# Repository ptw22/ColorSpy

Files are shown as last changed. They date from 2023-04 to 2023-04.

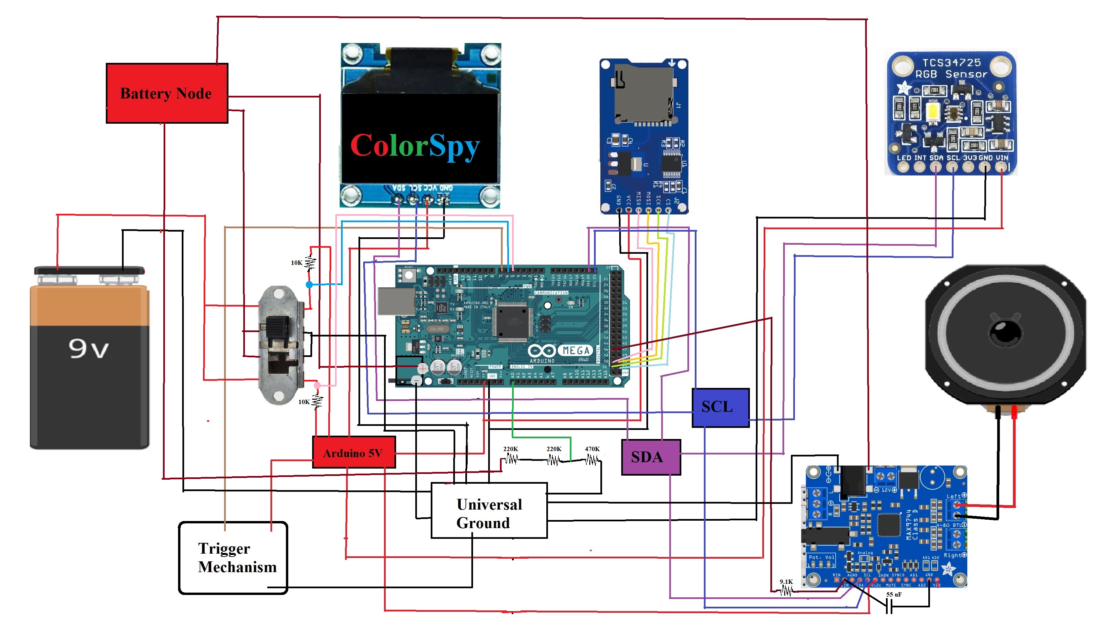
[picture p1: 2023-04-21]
colorpsydiagram.jpg

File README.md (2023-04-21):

# ColorSpy

Start with the ColorSpyInstructionManual file. Use the circuit diagram to guide you in building the circuit. Ensure relevant libraries are imported into your Arduino libraries folder. You can use the STL files to 3D print the housing for yourself.

*Disclaimer*: This project assumes the reader is familiar and experienced with safe soldering techniques, Arduino programming and battery handling. Always use best practices when handling electronic components, solder, soldering irons, and batteries. The uploaders of these files assume no liabilities for damaged micro controllers, injuries of other damage that may stem from accessing this information.

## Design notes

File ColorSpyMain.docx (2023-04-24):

#include "Wire.h"

#include "SPI.h"

#include "SD.h"

#include "TMRpcm.h"

#define SD_ChipSelectPin 53

#define MAX9744_I2CADDR 0x4B

#include "Adafruit_TCS34725.h"

#include <Adafruit_SSD1306.h>

#include <Adafruit_GFX.h>

#define OLED_ADDR 0x3C

Adafruit_SSD1306 display(-1);

int value; //value for the "voltage" read at analog pin

float voltage; //actual voltage after doing voltage divider calculations

float R1 = 44.0; //Resistor 1 value in voltage divider this is 440k for this i have two 220k in series

float R2 = 47.0; //Resistor 2 value in voltage divider this is 470k

int fullyDischargedVoltage=7; //fuly discharged voltage value for vattery

int fullyChargedVoltage=9; //fuly charged voltage value for vattery

int percentage; //percentage of battery remaining

int pin5; //initialization of pin 7

int pin6; //initialization of pin 6

TMRpcm tmrpcm;

int8_t thevol;

int val;

Adafruit_TCS34725 tcs = Adafruit_TCS34725(TCS34725_INTEGRATIONTIME_50MS, TCS34725_GAIN_1X);

//function to draw horizontal lines for battery

void drawLineH(int start, int end, int row) {

int i = start;

while (i <= end) {

display.drawPixel(i, row, WHITE); //command to display pixel (column, row, color)

i++; //We dont have color but it has to be there

}

}

//function to draw vertical lines for battery

void drawLineV(int start, int end, int column) {

int j = start;

while (j <= end) {

display.drawPixel(column, j, WHITE); //command to display pixel (column, row, color)

j++;

}

}

//function to draw battery border

void screenSetup(){

// code for the battery horizontal border

drawLineH(93, 126, 0);

drawLineH(93, 126, 7);

// code for the battery vertical border

drawLineV(1, 6, 92);

drawLineV(1, 6, 127);

// code for the battery tip

drawLineH(88, 91, 2);

drawLineH(88, 91, 3);

drawLineH(88, 91, 4);

drawLineH(88, 91, 5);

}

//function for the block 1 inside battery

void block1(){

drawLineH(95, 100, 2);

drawLineH(95, 100, 3);

drawLineH(95, 100, 4);

drawLineH(95, 100, 5);

}

//function for the block 2 inside battery

void block2(){

drawLineH(103, 108, 2);

drawLineH(103, 108, 3);

drawLineH(103, 108, 4);

drawLineH(103, 108, 5);

}

//function for the block 3 inside battery

void block3(){

drawLineH(111, 116, 2);

drawLineH(111, 116, 3);

drawLineH(111, 116, 4);

drawLineH(111, 116, 5);

}

//function for the block 4 inside battery

void block4(){

drawLineH(119, 124, 2);

drawLineH(119, 124, 3);

drawLineH(119, 124, 4);

drawLineH(119, 124, 5);

}

//function to measure voltage, do percentage calulcation, then display the corresponding number of blocks in the battery

void battery(){

value = analogRead(A0); //reads the value at the analog pin

voltage = 1.1 * value * (5.0/1024)*((R1 + R2)/R2); //1.04 is correction factor, 5/1024 is to get the bits or whatever multiplied by reciprocal of voltage divider

percentage = (voltage - fullyDischargedVoltage) / (fullyChargedVoltage - fullyDischargedVoltage) * 100; //calculated the percentage of the battery remaining

percentage = (percentage/10)*10; //This makes the percentage increment in increments of 10

screenSetup(); //calls screenSetup function to put the borders of the battery on the screen

if (percentage >= 80){

block1();

block2();

block3();

block4();

}

else if (percentage < 80 && percentage >= 60){

block2();

block3();

block4();

}

else if (percentage < 60 && percentage >= 40){

block3();

block4();

}

else if (percentage < 40 && percentage >= 20){

block4();

}

else if (percentage < 20 && percentage >= 0){

//empty on purpose

}

}

class ColorName { //creates a private class color name which will be used to create our predetermined color value objects.

protected: //safe variables that cannot be alterted by the sketch/ComputeMSE

String _name;

byte _red;

byte _green;

byte _blue;

public: //duplicate variables safe for manipulation

ColorName(String name, byte red, byte green, byte blue){

_name = name;

_red = red;

_green = green;

_blue = blue;

}

byte getRed(){ //gets protected variables and passes them into public domain

return _red;}

byte getGreen(){

return _green;}

byte getBlue(){

return _blue;}

String getName(){

return _name;}

long computeMse(byte red, byte green, byte blue) { //computes error between defined color and measured color using Mean square error method

return (long) (((long)(red - _red) * (red - _red) + (long)(green - _green) * (green - _green) + (long)(blue - _blue) * (blue - _blue)) / 3);

}

static ColorName* getClosestColorName(ColorName colorNames[],

unsigned int numColors, byte red, byte green, byte blue){ //takes in predetermined color array and predetermined color

//array size. also takes in measured RGB values

ColorName* _bestMatchColorName = NULL; //initializes best color name match pointer

long bestMatchDistance = 65535;

for(int i = 0; i < numColors; i++){ //iterate through all predetermined color objects and their values

ColorName* curColorName = &colorNames[i];

if(_bestMatchColorName == NULL){

_bestMatchColorName = &colorNames[0];

}

long meanSquareError = curColorName->computeMse(red, green, blue);

if(meanSquareError < bestMatchDistance){

_bestMatchColorName = &colorNames[i];

bestMatchDistance = meanSquareError;

}

}

return _bestMatchColorName;

}

};

const int NUM_COLOR_NAMES = 12; //defines the colors and their ideal values

ColorName _colorNames[NUM_COLOR_NAMES] = { //this can be adjusted to add more colors and better accuracy

ColorName("Purple", 78, 67, 102),

ColorName("Yellow", 106, 92, 42),

ColorName("Blue", 34, 88, 124),

ColorName("Green", 51, 114, 76),

ColorName("Red", 156, 47, 51),

ColorName("Black", 85, 84, 74),

ColorName("Orange", 157, 53, 36),

ColorName("White", 81, 85, 76),

ColorName("Brown", 112, 75, 58),

ColorName("Cyan", 50, 98, 96),

ColorName("Pink", 131, 55, 65),

ColorName("Lime", 80, 108, 51)

};

void setup() {

Serial.begin(9600); //Initializes Arduino

tmrpcm.speakerPin=46;

SD.begin(SD_ChipSelectPin); //Initialized SD Card

Wire.begin();

pinMode(6, INPUT);

pinMode(5, INPUT);

setvolume(60);

// initialize and clear display

display.begin(SSD1306_SWITCHCAPVCC, OLED_ADDR);

display.clearDisplay();

display.display(); //updates the display need this anytime you want to put something on the screen

float sensedRed, sensedGreen, sensedBlue;

tcs.getRGB(&sensedRed, &sensedGreen, &sensedBlue);

int rawRed = (int)sensedRed;

int rawGreen = (int)sensedGreen;

int rawBlue = (int)sensedBlue;

}

boolean setvolume(int8_t v) { //volume control function

Serial.println("accesses set volume function");

Wire.beginTransmission(MAX9744_I2CADDR);

Serial.println("begins volume transmission");

Wire.write(v);

Serial.println("writes volume");

if (Wire.endTransmission() == 0)

return true;

else

return false;

}

char hex(int n) {

if (n < 10) {

return char(n + 48); // 48 is the ASCII code for '0'

} else {

return char(n + 55); // 55 is the ASCII code for 'A' - 10

}

}

String RGBtoHex(int r, int g, int b) {

String hexCode = "";

hexCode += hex(r / 16);

hexCode += hex(r % 16);

hexCode += hex(g / 16);

hexCode += hex(g % 16);

hexCode += hex(b / 16);

hexCode += hex(b % 16);

return hexCode;

}

ColorName *closestColorName = nullptr; //added this so we can call it in the later if statements

String hexCode = "";

float R; float G; float B; int Rcomp; int Gcomp; int Bcomp;

void loop() {

pin5 = digitalRead(5);

pin6 = digitalRead(6);

if (pin6 == LOW && pin5 == HIGH) {

if (digitalRead(7) == HIGH) {

uint16_t r, g, b, c; //variables for rgb and clear

tcs.getRawData(&r, &g, &b, &c); //stores the data inside the variables

R = (float)r / (float)c;

G = (float)g / (float)c;

B = (float)b / (float)c;

R *= 255; G *= 255; B *= 255;

R = map(R, 41, 112, 0, 255); //USES THE MAP FUNCTION TO SKEW THE VALUES THE SENSOR MEASURES:

G = map(G, 46, 105, 0, 255); //THE 2ND VALUES OF THE MAP FUNCTION CAN BE FURTHER TUNED TO INSCREASE ACCURACY

B = map(B, 51,91, 0, 255);

Rcomp = constrain(R,0,255); //CONSTRAINS VALUES BETWEEN 0 and 255 IN CASE MAP FUNCTION THROWS IT OUTSIDE THAT RANGE

Gcomp = constrain(G,0,255);

Bcomp = constrain(B,0,255);

hexCode = RGBtoHex((int)Rcomp,(int)Gcomp,(int)Bcomp);

delay(100);

}

display.clearDisplay();

battery(); //call battery function to display the battery

display.setTextSize(1); //set text size for the text to be printed

display.setTextColor(WHITE); //set color of text

display.setCursor(0,0); //sets the starting location of the text (column, row)

display.print("MODE: ADVANCED"); //text to display

display.setTextSize(1);

display.setTextColor(WHITE);

display.setCursor(0,9);

display.print("R:");

display.setCursor(17,9);

display.print((int)Rcomp);

display.setCursor(45,9);

display.print("G:");

display.setCursor(60,9);

display.print((int)Gcomp);

display.setCursor(85,9);

display.print("B:");

display.setCursor(100,9);

display.print((int)Bcomp);

display.setTextSize(1);

display.setTextColor(WHITE);

display.setCursor(0, 23);

display.print("HEXCODE:");

display.setTextSize(2);

display.setTextColor(WHITE);

display.setCursor(52, 18);

display.print(hexCode);

delay(1);

display.display();

}

else if (pin5 == LOW && pin6 == HIGH) {

if (digitalRead(7) == HIGH) {

float sensedRed, sensedGreen, sensedBlue;

tcs.getRGB(&sensedRed, &sensedGreen, &sensedBlue);

int rawRed = (int)sensedRed;

int rawGreen = (int)sensedGreen;

int rawBlue = (int)sensedBlue;

Serial.print("Red: ");

Serial.println(rawRed);

Serial.print("Green: ");

Serial.println(rawGreen);

Serial.print("Blue: ");

Serial.println(rawBlue);

closestColorName = ColorName::getClosestColorName(_colorNames, NUM_COLOR_NAMES, rawRed, rawGreen, rawBlue);

Serial.println(closestColorName->getName());

String sound = closestColorName->getName() + ".wav";

char *char_array = new char[sound.length() + 1];

strcpy(char_array, sound.c_str());

tmrpcm.play(char_array);

delay(50);

}

display.clearDisplay();

battery();

display.setTextSize(1);

display.setTextColor(WHITE);

display.setCursor(0, 0);

display.print("MODE:");

display.setTextSize(1);

display.setTextColor(WHITE);

display.setCursor(0, 8);

display.print("NORMAL");

display.setTextSize(1);

display.setTextColor(WHITE);

display.setCursor(0, 23);

display.print("COLOR:");

if (closestColorName != nullptr) { // Check if closestColorName has been initialized

display.setCursor(40, 23);

display.print(closestColorName->getName());

delay(1);

}

display.display();

}

}

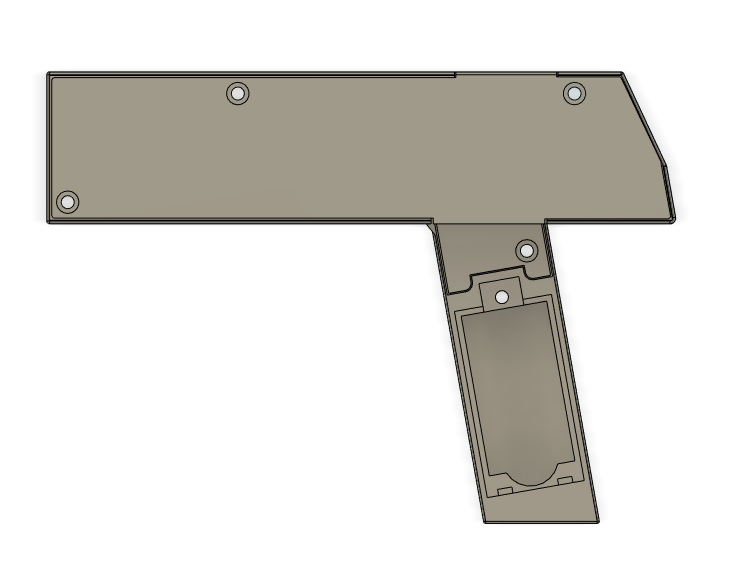
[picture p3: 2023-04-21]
3D product visualization/Fusion360_PE8MGMYq69.png

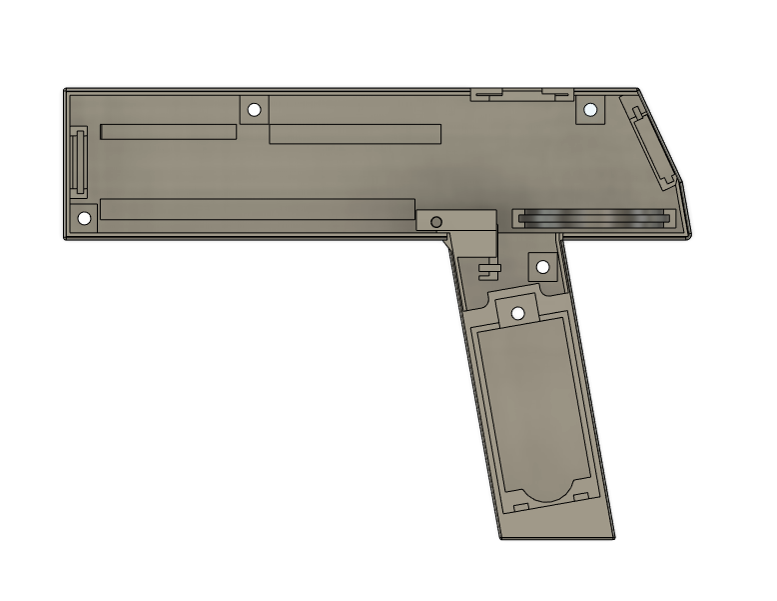
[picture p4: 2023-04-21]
3D product visualization/Fusion360_0vmRuYJ2hL.png

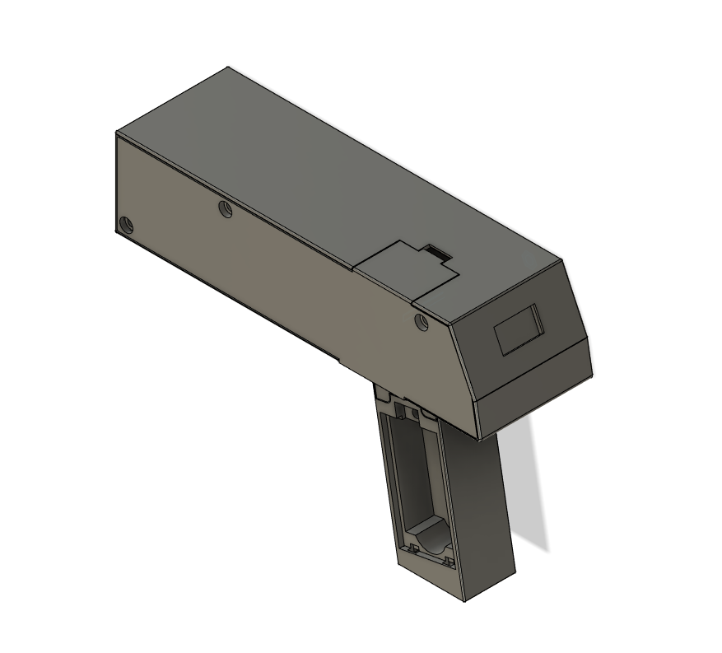
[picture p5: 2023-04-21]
3D product visualization/Fusion360_oO8stzrLVn.png

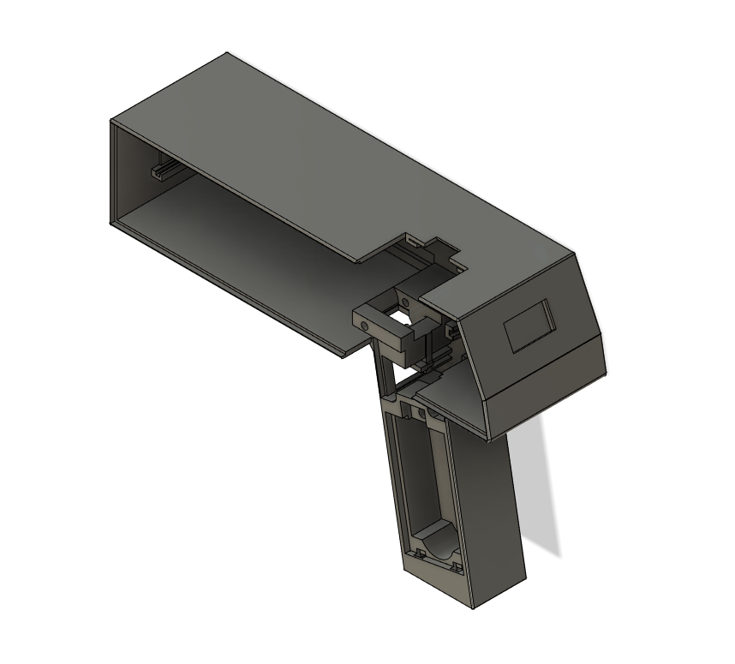
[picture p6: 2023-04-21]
3D product visualization/Fusion360_ESraKVEtEX.png

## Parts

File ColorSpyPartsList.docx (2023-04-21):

Parts List:

Arduino Mega (microcontroller)

MAX9744 (DAC/Amp, used to increase speaker volume, grant adjustable volume capabilities and output higher quality human speech. Can be omitted if the user is not interested high quality sound, in that case ensure correct wiring of speaker to Ardunio Pin)

OLED (device's display):

SD Card module (holds audio files, adds capabilities for more audio files to be added in the future.)

TCS34725 (Adafruit RGB color sensor)

Resistors (220K x 2, 470K x 1, 10K x 2, 9.1K, x 1)

Capacitor (55 uF x 1)

2W 8Ohm speaker

3 position slide switch

Wires (12 feet)

BreadBoard (recommended for debugging and testing prior to hardwiring all components)

3D print filament: 200 g, PLA (if 3D housing is desired)

MicroSD Card (12-32GB)

Estimated Total cost: $65 based on individual component prices

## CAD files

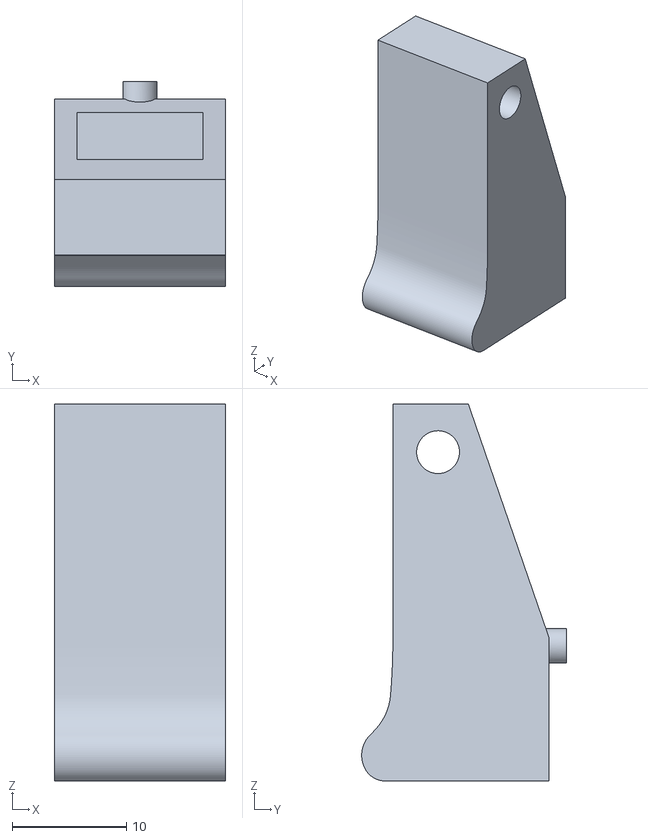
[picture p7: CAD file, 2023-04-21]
STL Files for 3D Print/V1Button.stl
15.0 x 17.9 x 33.0

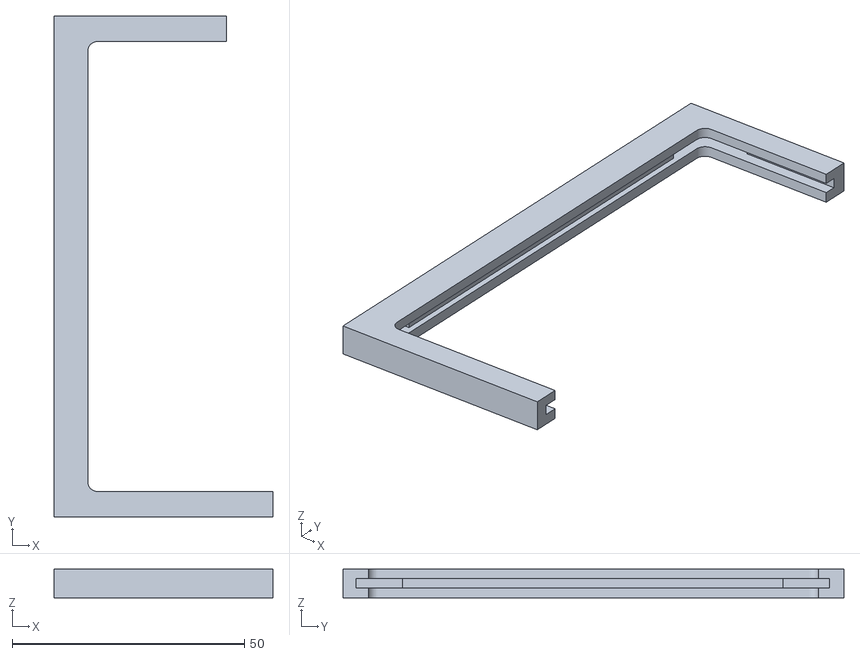
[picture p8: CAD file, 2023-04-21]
STL Files for 3D Print/V1Mega.stl
47.0 x 107.8 x 6.15

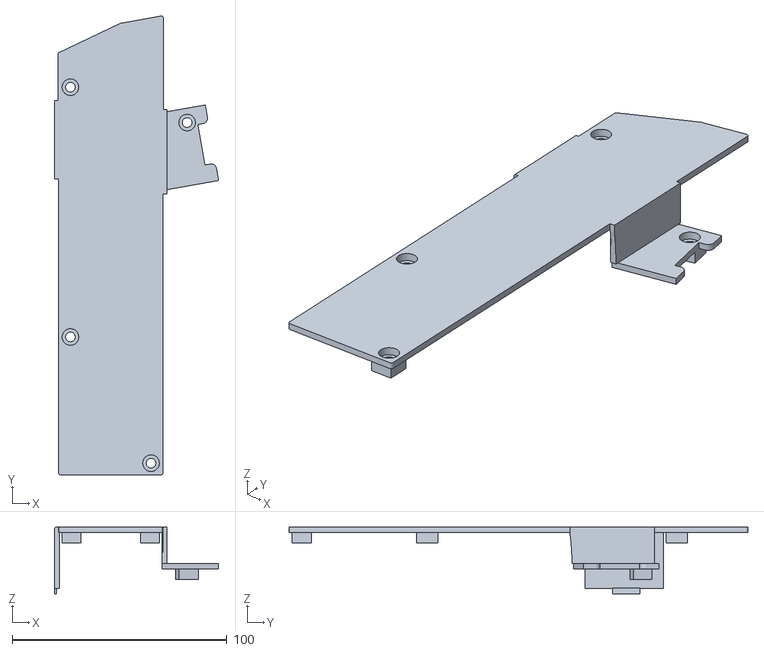
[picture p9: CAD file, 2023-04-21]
STL Files for 3D Print/Fixed Cover.stl
76.5 x 213.6 x 31.1

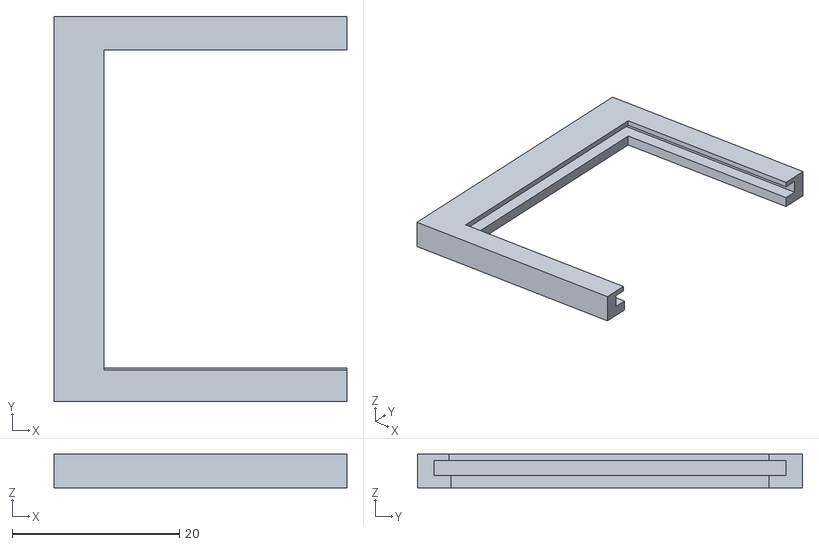
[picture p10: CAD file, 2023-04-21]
STL Files for 3D Print/V1SD.stl
35.0 x 46.0 x 4.05

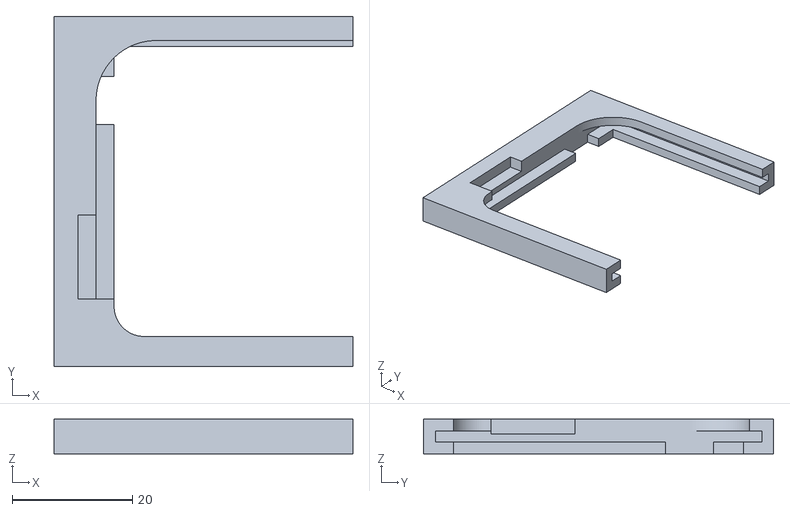
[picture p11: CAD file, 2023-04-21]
STL Files for 3D Print/V1DAC.stl
49.8 x 58.2 x 5.75

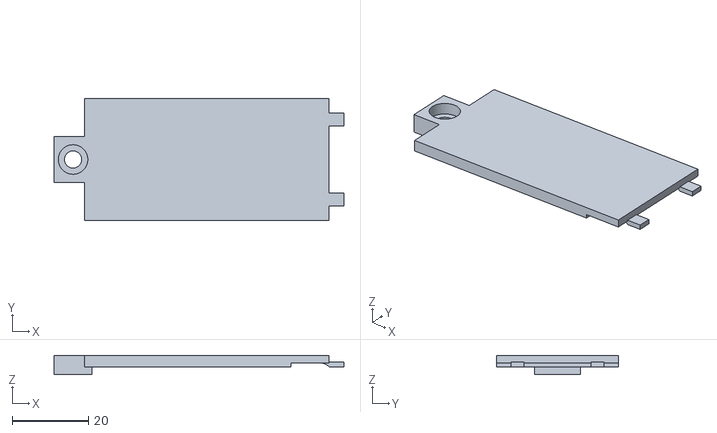
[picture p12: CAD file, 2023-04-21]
STL Files for 3D Print/V2Batery.stl
76.0 x 32.0 x 5.00

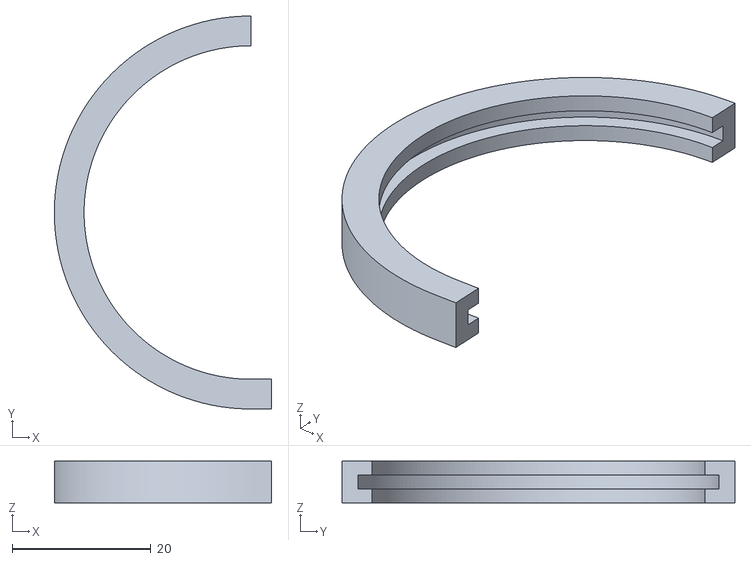
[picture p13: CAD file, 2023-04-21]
STL Files for 3D Print/V1Speaker.stl
31.3 x 56.6 x 6.00

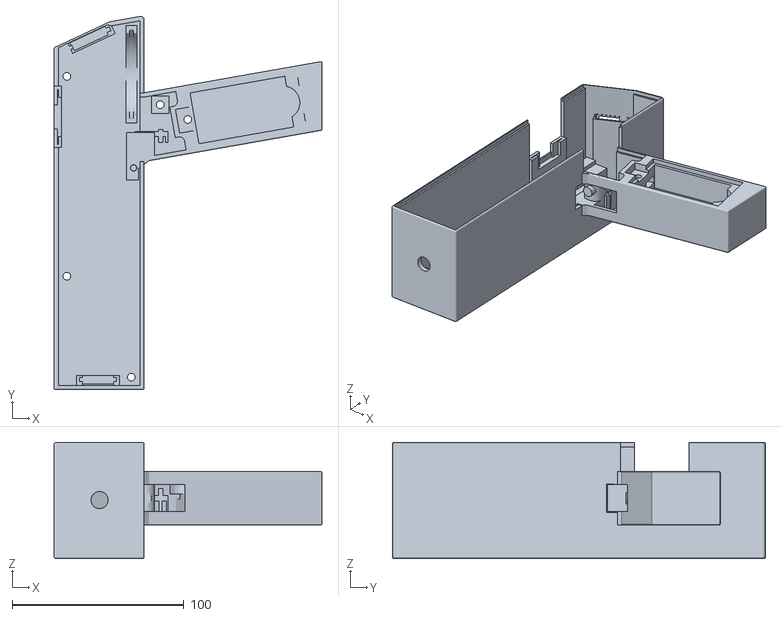
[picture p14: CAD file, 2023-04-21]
STL Files for 3D Print/FColorspy.stl
155.9 x 217.1 x 67.5

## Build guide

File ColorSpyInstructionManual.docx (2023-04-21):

ColorSpy Instruction Manual

*Disclaimer*: This project assumes the reader is familiar and experienced with safe soldering techniques, Arduino programming and battery handling. Always use best practices when handling electronic components, solder, soldering irons, and batteries. The uploaders of these files assume no liabilities for damaged micro controllers, injuries or other damage that may stem from accessing this information.

*MICRO-CONTROLLER REQUIREMENT*: This project was designed using the Ardunio Mega 2560 microcontroller because of it’s program space. Other microcontrollers may or may not work, substitute at your own risk.

*DEVICE ALTERATION NOTE*: There are two adafruit components that were altered in the making of this project; (1): the Ardunio Mega 2560 has the power jack removed and wire leads directly soldered to the positive and negative terminals. (2) the MAX9744 power jack is also removed from the component and the positive and negative wire lead directly soldered to the terminals. You can avoid this part by using power jack connections with the 2 wires stripped and soldered to the correct nodes, the makers of this project altered the components in the interest of space saving. If the reader is not comfortable with altering the components, using the power jacks is highly recommended.

Part 1: Ardunio code set up

Navigate to your Ardunio libraries fold. On windows its C:// -> Documents -> Ardunio -> libraries. Ensure that you have the libraries:

Adafruit_BusIO

Adafruit_GFX_Library

Adafruit_SSD1306

Adafruit_TCS34725

OneWire – 2.3.7

TMRpcm

inside your Arduio libraries folder. If you’re missing any of them you can download them from the ColorSpy github repositor. Next open up your Ardunio IDE and configure it for the Ardunio MEGA 2560. Open up the text document labeled ColorSpyMain.docx. Copy and paste the contents of the ColorSpyMain.docx into your IDE. Click on verify. Barring any incompatibilities, the code should compile directly. Debug as needed.

At the same time as you are implementing the software, download the ColorAudioFiles.zip file and extract the audio files onto your SD card. After the audio files are transferred you can insert it into the SD Card module.

Part 2: Hardware Setup

Access the parts list docx file in the repository and ensure you have all the components necessary for this project. DigiKey, Amazon and Adafruit were all distributors that the makers of this project used. Then use the colorspydiagram.jpg diagram to guide you in making the correct connections. Ensure all connections are made exactly according to the diagram, as deviation may cause misoperation and damage.

Part 3: Testing

After the software has be succeffully compiled and the hardware portion has been implemented; upload the code to the board. After uploading you can disconnect the usb to the computer and the entire circuit should work from the 9V battery. Use the OLED screen to to ensure the device operates in both modes (Normal and Advanced). Confirm speaker outputs the human sound.

Part 4: 3D housing (optional)

Download the STL files for the 3D print housing and convert to your preferred obj. format. Print out parts for the housing, you can use the folder labeled 3D product visualization to allow you to preview the device design. You’ll notice small rail systems inside the housing, these are included to allow you slide each of the breakout boards into the housing to secure them. Wire minimization may have to take place to fit everything inside the housing.
